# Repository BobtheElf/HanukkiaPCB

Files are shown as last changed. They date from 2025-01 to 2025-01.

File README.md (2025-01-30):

# HanukkiaPCB
This is a PCB I designed on Eagle for my family and all of the good people at Mines Hillel. All of this is free to use and I encourage better designs. I used AutoCad Eagle to design the schematic and PCB, but if you would like to print the board as-is, I have included the most current gerber files.

## More Details
This circuit is based off Dr. Chris Coulston's VU-meter circuit, and should only need a 5V USB-C power source to work. Simply plug in the board with appropriate parts soldered, and turn the potentiometer to the correct day of Hanukkah. Beware that different batches of LM324 op-amps can misbehave in this circuit.

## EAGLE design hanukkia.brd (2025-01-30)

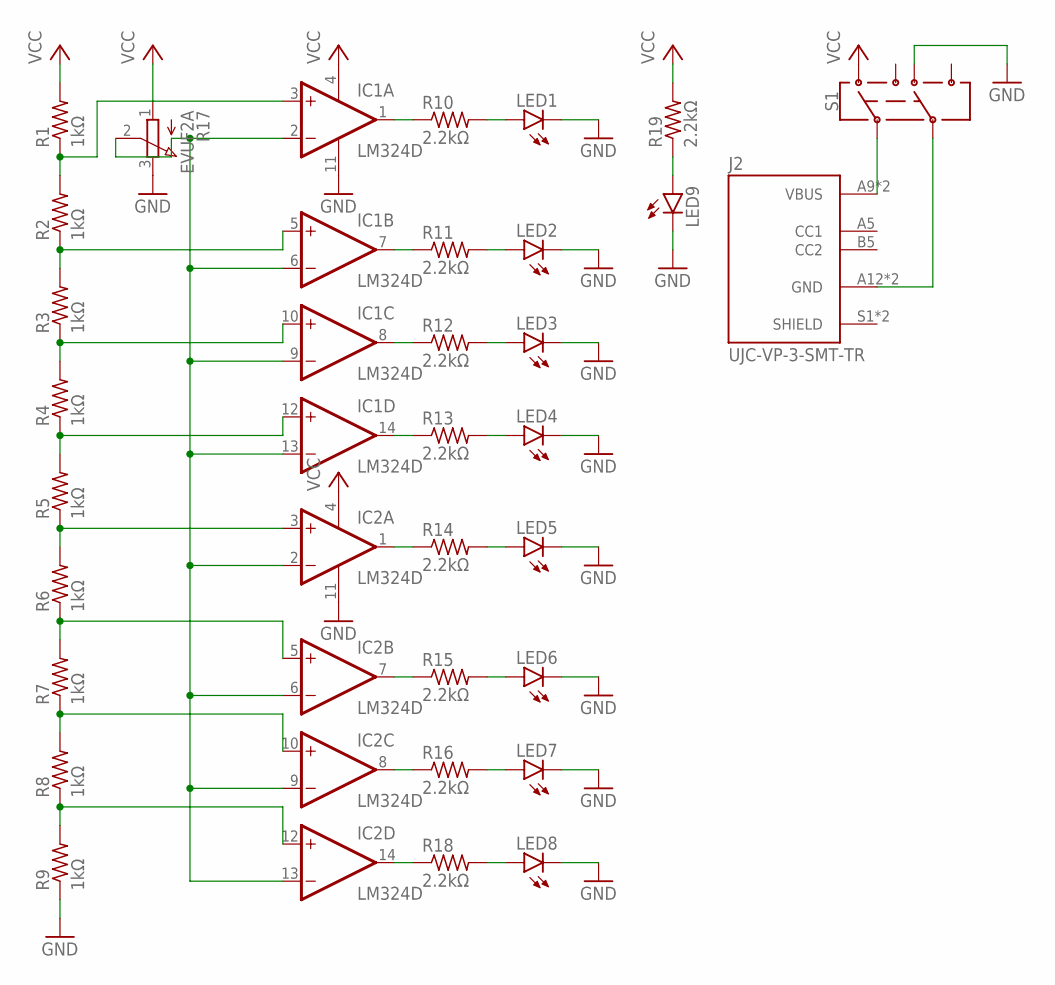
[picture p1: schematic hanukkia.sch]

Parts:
IC1, IC2: LM324D; SO14
J2: UJC-VP-3-SMT-TR; CUI_UJC-VP-3-SMT-TR
LED1, LED2, LED3, LED4, LED5, LED6, LED7, LED8, LED9: LEDCHIPLED_1206; CHIPLED_1206
R1, R2, R3, R4, R5, R6, R7, R8, R9: 1kΩ; R1206
R10, R11, R12, R13, R14, R15, R16, R18, R19: 2.2kΩ; R1206
R17: EVUF2A; EVUF
S1: SWITCH-DPDT-SMD-AYZ0202; SWITCH_DPDT_SMD_AYZ0202

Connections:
GND: IC1.11 (V-), IC2.11 (V-), LED1.C, LED2.C, LED3.C, LED4.C, LED5.C, LED6.C, LED7.C, LED8.C, LED9.C, R9.1, R17.3 (E), S1.6
unnamed: IC1.3 (+IN), R1.1, R2.2
unnamed: IC1.5 (+IN), R2.1, R3.2
unnamed: IC1.10 (+IN), R3.1, R4.2
unnamed: IC1.12 (+IN), R4.1, R5.2
unnamed: IC2.3 (+IN), R5.1, R6.2
unnamed: IC2.5 (+IN), R6.1, R7.2
unnamed: IC2.10 (+IN), R7.1, R8.2
unnamed: IC2.12 (+IN), R8.1, R9.2
unnamed: IC1.2 (-IN), IC1.6 (-IN), IC1.9 (-IN), IC1.13 (-IN), IC2.2 (-IN), IC2.6 (-IN), IC2.9 (-IN), IC2.13 (-IN), R17.2 (S)
unnamed: IC1.1 (OUT), R10.1
unnamed: LED1.A, R10.2
unnamed: LED2.A, R11.2
unnamed: IC1.7 (OUT), R11.1
unnamed: IC1.8 (OUT), R12.1
unnamed: LED3.A, R12.2
unnamed: IC1.14 (OUT), R13.1
unnamed: LED4.A, R13.2
unnamed: IC2.1 (OUT), R14.1
unnamed: LED5.A, R14.2
unnamed: IC2.7 (OUT), R15.1
unnamed: LED6.A, R15.2
unnamed: IC2.8 (OUT), R16.1
unnamed: LED7.A, R16.2
unnamed: IC2.14 (OUT), R18.1
unnamed: LED8.A, R18.2
unnamed: LED9.A, R19.1
unnamed: J2.A9 (VBUS), J2.B9 (VBUS), S1.2
unnamed: J2.A12 (GND), J2.B12 (GND), S1.5
VCC: IC1.4 (V+), IC2.4 (V+), R1.2, R17.1 (A), R19.2, S1.3

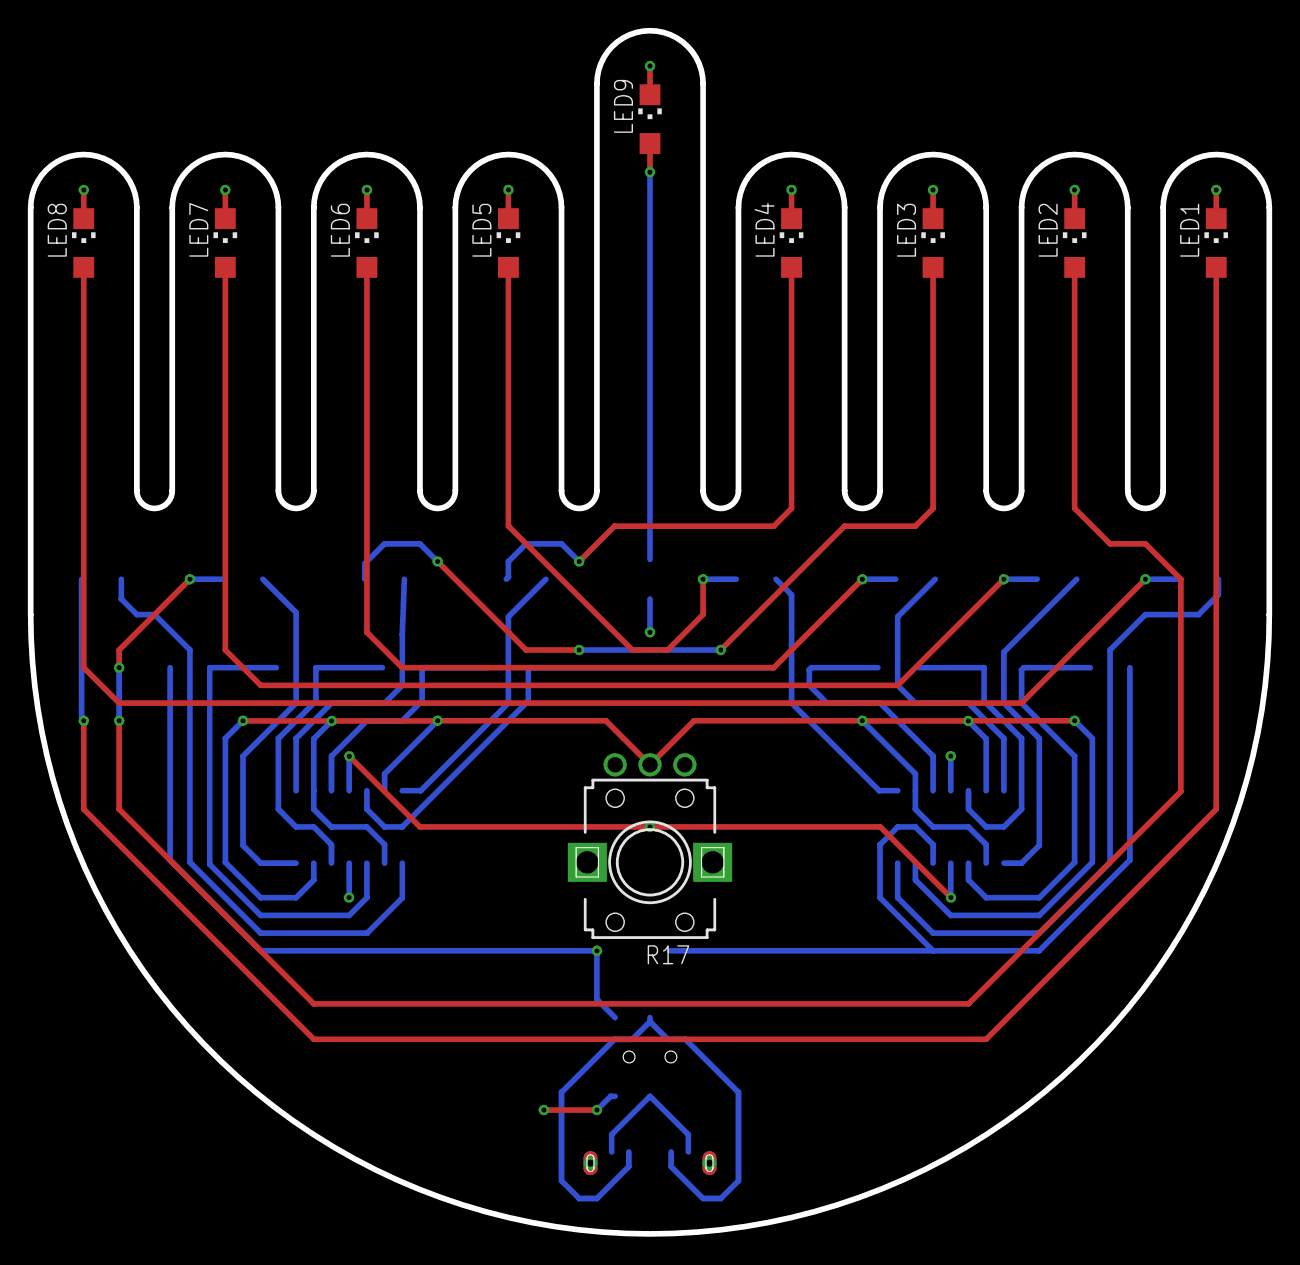
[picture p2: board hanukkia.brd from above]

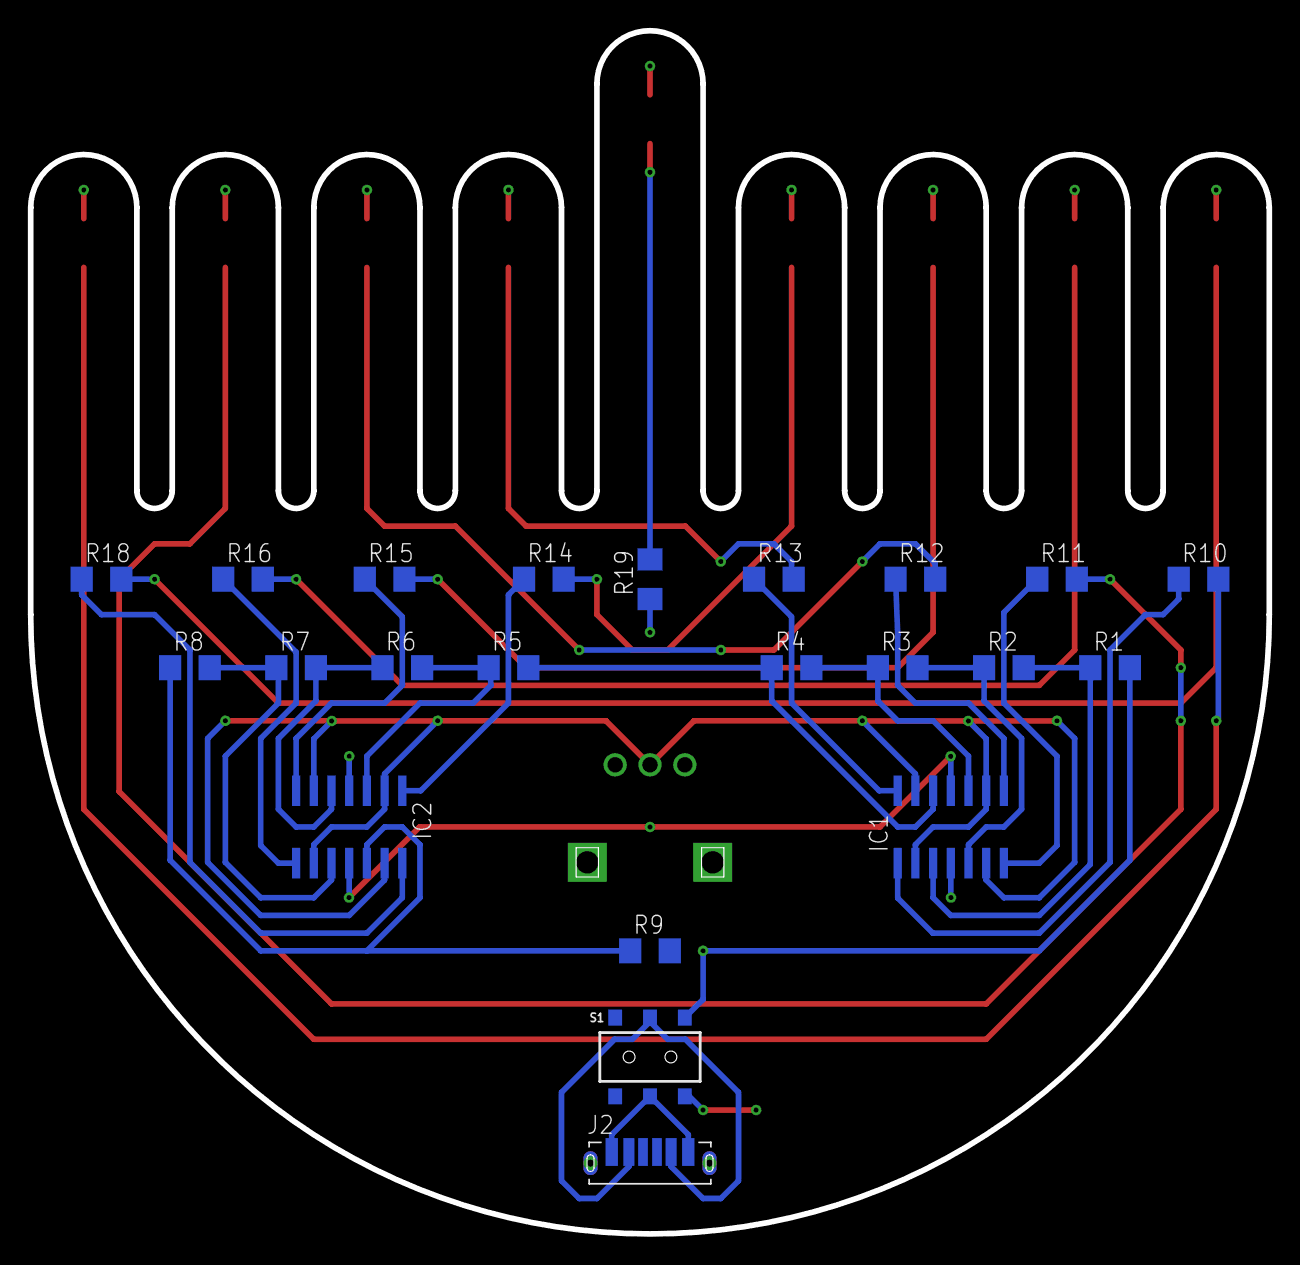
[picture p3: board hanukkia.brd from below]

Board: 2 copper layers, 88.9 x 86.4 mm, 32 parts (22 on the bottom side), 30 nets.

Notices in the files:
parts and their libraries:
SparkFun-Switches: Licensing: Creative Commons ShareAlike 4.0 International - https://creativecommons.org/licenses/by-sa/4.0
